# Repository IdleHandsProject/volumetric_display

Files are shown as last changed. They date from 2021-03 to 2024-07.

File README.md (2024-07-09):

# TENEX - Open Source Volumetric OLED Display

## Check out the video! - Click the Image

Volumetric OLED Display on Youtube (https://youtu.be/sVv1oc14X1w)

Control up to ten transparent OLED displays using your favourite Feather board.

Find the BOM here: https://www.findchips.com/org/10-open-hardware/list/208915-tenex-project

Shield: [][cc-by-sa]

This work is licensed under a
[Creative Commons Attribution-ShareAlike 4.0 International License][cc-by-sa].

[][cc-by-sa]

[cc-by-sa]: http://creativecommons.org/licenses/by-sa/4.0/
[cc-by-sa-image]: https://licensebuttons.net/l/by-sa/4.0/88x31.png
[cc-by-sa-shield]: https://img.shields.io/badge/License-CC%20BY--SA%204.0-lightgrey.svg

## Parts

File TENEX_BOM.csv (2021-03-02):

Manufacturer Part Number | Manufacturer | Digi-Key Part Number | Customer Reference | Reference Designator | Packaging | Part Status | Quantity | Unit Price | Extended Price | Quantity Available | Mfg Std Lead Time | Description | RoHS Status | Lead Free Status | REACH Status
CC0805MRX7R8BB104 | Yageo | 311-4348-1-ND | C3 C6 C8 C12 C15 C17 C24 C30 |  | Cut Tape (CT) | Active | 8 | 0.16000 | $1.28 | 764 | 20 Weeks | CAP CER 0.1UF 25V X7R 0805 | ROHS3 Compliant | Lead free | REACH Unaffected
CC0805MKX7R8BB475 | Yageo | 311-3509-2-ND | C4 C7 C9 C10 C13 C16 C19 C22 C25 C28 C31 |  | Tape & Reel (TR) | Active | 11 | 0.00000 | $0.00 | 9539 | 24 Weeks | CAP CER 4.7UF 25V X7R 0805 | ROHS3 Compliant | Lead free | REACH Unaffected
CC0805KKX5R8BB106 | Yageo | 311-1869-1-ND | C1 C5 C11 C14 C23 C29 |  | Cut Tape (CT) | Active | 6 | 0.72000 | $4.32 | 618478 | 52 Weeks | CAP CER 10UF 25V X5R 0805 | ROHS3 Compliant | Lead free | REACH Unaffected
CC0805MKX5R5BB226 | Yageo | 311-1464-1-ND | C2 |  | Cut Tape (CT) | Active | 1 | 0.77000 | $0.77 | 151111 | 24 Weeks | CAP CER 22UF 6.3V X5R 0805 | ROHS3 Compliant | Lead free | REACH Unaffected
NSVRB521S30T1G | ON Semiconductor | NSVRB521S30T1GOSCT-ND | D1 |  | Cut Tape (CT) | Active | 1 | 0.54000 | $0.54 | 0 | 46 Weeks | DIODE SCHOTTKY 30V 200MA SOD523 | ROHS3 Compliant | Lead free | REACH Unaffected
694106301002 | Würth Elektronik | 732-5930-ND | J1 |  | Bulk | Active | 1 | 1.30000 | $1.30 | 356 | 10 Weeks | CONN PWR JACK 2.1X5.5MM SOLDER | ROHS3 Compliant | Lead free | REACH Unaffected
PS1240P02BT | TDK Corporation | 445-2525-1-ND | LS1 |  | Cut Tape (CT) | Active | 1 | 0.88000 | $0.88 | 25024 | 8 Weeks | AUDIO PIEZO TRANSDUCER 30V TH | ROHS3 Compliant | Lead free | Not Available
RC0805JR-07470RL | Yageo | 311-470ARCT-ND | R29 |  | Cut Tape (CT) | Active | 1 | 0.14000 | $0.14 | 663861 | 20 Weeks | RES SMD 470 OHM 5% 1/8W 0805 | ROHS3 Compliant | Lead free | REACH Unaffected
RT0805FRE074K7L | Yageo | YAG3364CT-ND | R26 R27 R28 |  | Cut Tape (CT) | Active | 3 | 0.14000 | $0.42 | 12032 | 20 Weeks | RES SMD 4.7K OHM 1% 1/8W 0805 | ROHS3 Compliant | Lead free | REACH Unaffected
AC0805FR-0724KL | Yageo | 13-AC0805FR-0724KLCT-ND | R20 |  | Cut Tape (CT) | Active | 1 | 0.14000 | $0.14 | 2490 | 20 Weeks | RES SMD 24K OHM 1% 1/8W 0805 | ROHS3 Compliant | Lead free | REACH Unaffected
RT0805FRE0775KL | Yageo | 13-RT0805FRE0775KLCT-ND | R18 |  | Cut Tape (CT) | Active | 1 | 0.14000 | $0.14 | 3596 | 20 Weeks | RES SMD 75K OHM 1% 1/8W 0805 | ROHS3 Compliant | Lead free | REACH Unaffected
RMCF0805FG100K | Stackpole Electronics Inc | RMCF0805FG100KCT-ND | R2 R3 R4 R5 R6 R7 R8 R9 R10 R11 |  | Cut Tape (CT) | Active | 10 | 0.03800 | $0.38 | 29256 | 21 Weeks | RES 100K OHM 1% 1/8W 0805 | ROHS3 Compliant | Lead free | REACH Unaffected
RMCF0805FG100K | Stackpole Electronics Inc | RMCF0805FG100KCT-ND | R17 R19 |  | Cut Tape (CT) | Active | 2 | 0.03800 | $0.38 | 29256 | 21 Weeks | RES 100K OHM 1% 1/8W 0805 | ROHS3 Compliant | Lead free | REACH Unaffected
RC0805FR-075K1L | Yageo | 311-5.10KCRCT-ND | R1 |  | Cut Tape (CT) | Active | 1 | 0.14000 | $0.14 | 1557587 | 20 Weeks | RES SMD 5.1K OHM 1% 1/8W 0805 | ROHS3 Compliant | Lead free | REACH Unaffected
RC0805FR-07910KL | Yageo | YAG3336CT-ND | R12 R13 R14 R15 R16 R21 R22 R23 R24 R25 |  | Cut Tape (CT) | Active | 10 | 0.05800 | $0.58 | 1287 | 20 Weeks | RES SMD 910K OHM 1% 1/8W 0805 | ROHS3 Compliant | Lead free | REACH Unaffected
MPM3606AGQV-P | Monolithic Power Systems Inc. | 1589-1247-1-ND | U7 |  | Cut Tape (CT) | Active | 1 | 4.18000 | $4.18 | 1870 | 16 Weeks | DC DC CONVERTER 0.8-18.48V | ROHS3 Compliant | Lead free | REACH Unaffected
MPU-6050 | TDK InvenSense | 1428-1007-1-ND | U13 |  | Cut Tape (CT) | Not For New Designs | 1 | 10.92000 | $10.92 | 5786 | 22 Weeks | IMU ACCEL/GYRO 3-AXIS I2C 24QFN | ROHS3 Compliant | Lead free | Not Available
62674-241121ALF | Amphenol ICC (FCI) | 609-1210-1-ND | U2 U3 U4 U5 U6 U8 U9 U10 U11 U12 |  | Cut Tape (CT) | Active | 10 | 0.99500 | $9.95 | 0 | 17 Weeks | CONN FFC VERT 24POS 0.50MM SMD | RoHS Compliant | Lead free | REACH Unaffected
3857 | Adafruit Industries LLC | 1528-2648-ND | U1 |  | Bulk | Active | 1 | 31.18000 | $31.18 | 284 | 2 Weeks | FEATHER M4 EXPRESS ATSAMD51J19 | ROHS3 Compliant | Not Available | Not Available

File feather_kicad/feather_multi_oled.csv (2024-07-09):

Source: | N:\idlehandsdev\Projects\volumetric_display\feather_kicad\feather_multi_oled.kicad_sch
Date: | 2024-07-09 9:34:55 AM
Tool: | Eeschema 7.0.9
Generator: | C:\Program Files\KiCad\7.0\bin\scripting\plugins/bom_csv_grouped_by_value.py
Component Count: | 71
Collated Components:
Item | Qty | Reference(s) | Value | LibPart | Footprint | Datasheet | DNP | Digikey Part No.
1 | 6 | C1, C5, C11, C14, C23, C29 | 10uF | Device:C_Small | Capacitor_SMD:C_0805_2012Metric | ~ |  | 311-1869-1-ND
2 | 1 | C2 | 22uF | Device:C_Small | Capacitor_SMD:C_0805_2012Metric | ~ |  | 311-1464-1-ND
3 | 8 | C3, C6, C8, C12, C15, C17, C24, C30 | 0.1uF | Device:C_Small | Capacitor_SMD:C_0805_2012Metric | ~ |  | 311-4348-1-ND
4 | 11 | C4, C7, C9, C10, C13, C16, C19, C22, C25, C28, C31 | 4.7uF | Device:C_Small | Capacitor_SMD:C_0805_2012Metric | ~ |  | 311-3509-2-ND
5 | 1 | D1 | RB521S30T1G | Device:D_Schottky_Small | Diode_SMD:D_SOD-523 | ~ |  | NSVRB521S30T1GOSCT-ND
6 | 1 | J1 | Barrel_Jack_Switch | Connector:Barrel_Jack_Switch | Connector_BarrelJack:BarrelJack_Wuerth_6941xx301002 | ~ |  | 732-5930-ND
7 | 1 | LS1 | Speaker_Crystal | Device:Speaker_Crystal | Buzzer_Beeper:Buzzer_TDK_PS1240P02BT_D12.2mm_H6.5mm | ~ |  | 445-2525-1-ND
8 | 1 | R1 | 5.1K 1% | Device:R_Small | Resistor_SMD:R_0805_2012Metric | ~ |  | 311-5.10KCRCT-ND
9 | 12 | R2, R3, R4, R5, R6, R7, R8, R9, R10, R11, R17, R19 | 100K | AP2112k:R_Small | Resistor_SMD:R_0805_2012Metric | ~ |  | RMCF0805FG100KCT-ND
10 | 10 | R12, R13, R14, R15, R16, R21, R22, R23, R24, R25 | 910K 1% | Device:R_Small | Resistor_SMD:R_0805_2012Metric | ~ |  | YAG3336CT-ND
11 | 1 | R18 | 75K | AP2112k:R_Small | Resistor_SMD:R_0805_2012Metric |  |  | 13-RT0805FRE0775KLCT-ND
12 | 1 | R20 | 24K | AP2112k:R_Small | Resistor_SMD:R_0805_2012Metric |  |  | 13-AC0805FR-0724KLCT-ND
13 | 3 | R26, R27, R28 | 4.7K | Device:R_Small | Resistor_SMD:R_0805_2012Metric | ~ |  | YAG3364CT-ND
14 | 1 | R29 | 470R | Device:R_Small | Resistor_SMD:R_0805_2012Metric | ~ |  | 311-470ARCT-ND
15 | 1 | U1 | feather | project_lib:feather | Adafruit_FeatherWing:PCB_FeatherWing |  |  | 1528-2648-ND
16 | 10 | U2, U3, U4, U5, U6, U8, U9, U10, U11, U12 | SSD1309_transparent_oled | project_lib:SSD1309_transparent_oled | project_footprints:FCI_62674-241121ALF |  |  | WM7986CT-ND
17 | 1 | U7 | MPM36XX | project_lib:MPM36XX | project_footprints:MPM3606AGQV-Z | https://www.monolithicpower.com/en/documentview/productdocument/index/version/2/document_type/Datasheet/lang/en/sku/MPM3606AGQV/document_id/2104 |  | 1589-1247-1-ND
18 | 1 | U13 | MPU-6050 | feather_multi_oled-rescue:MPU-6050-Sensor_Motion | Sensor_Motion:InvenSense_QFN-24_4x4mm_P0.5mm | https://store.invensense.com/datasheets/invensense/MPU-6050_DataSheet_V3%204.pdf |  | 1428-1007-1-ND

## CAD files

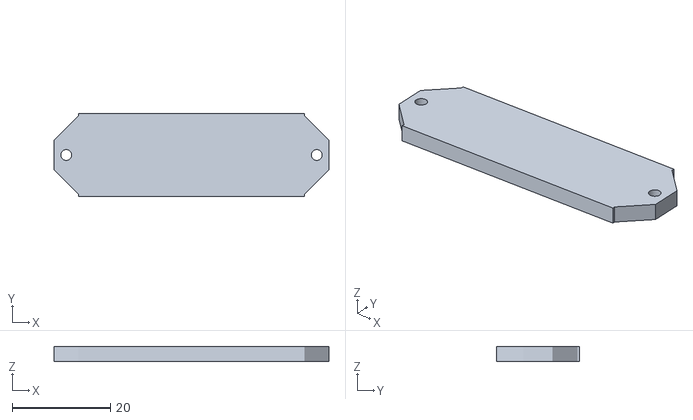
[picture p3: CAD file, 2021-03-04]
CAD/Display_Top (lasercut if possible).stl
56.0 x 17.0 x 3.00

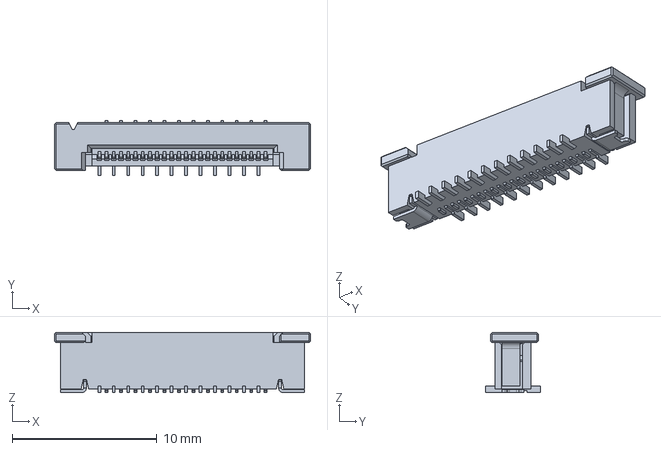
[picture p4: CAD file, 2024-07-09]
feather_kicad/project_libs/3dPackages/c-2-1734742-4-o-3d.stp
17.7 x 3.80 x 4.15 mm

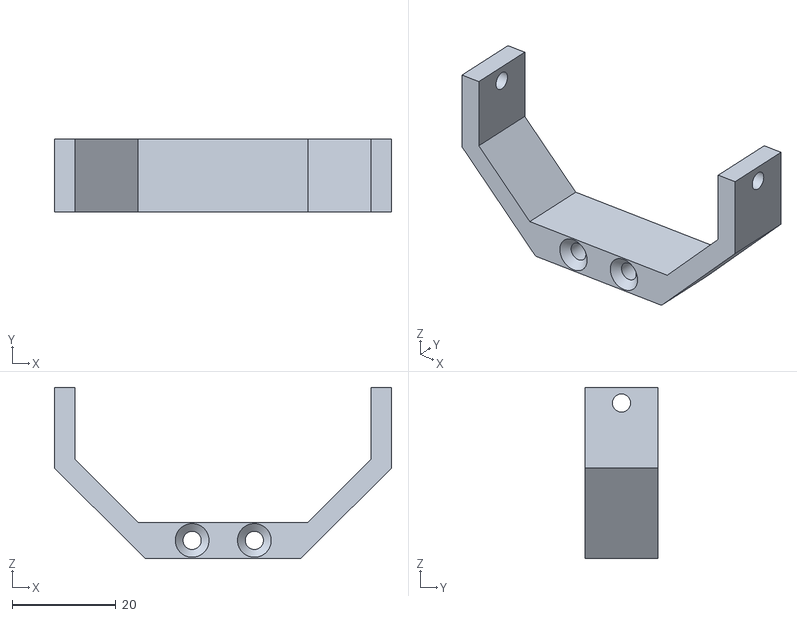
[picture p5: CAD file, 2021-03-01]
CAD/Head_Arm.stl
65.0 x 14.0 x 33.0

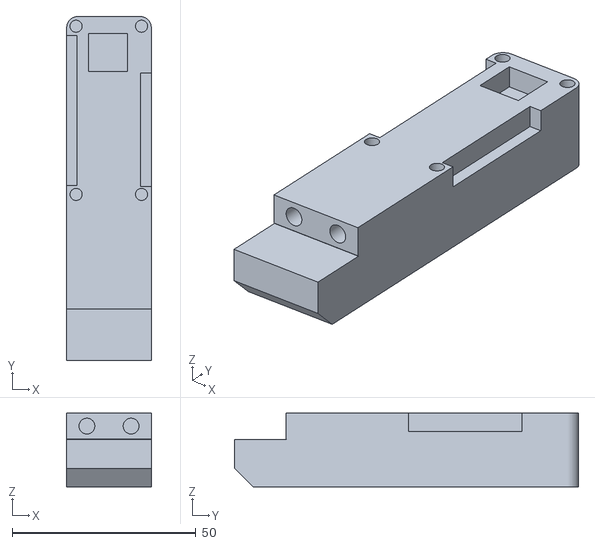
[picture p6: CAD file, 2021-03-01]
CAD/Head_Holder_Single.stl
23.0 x 93.5 x 20.0

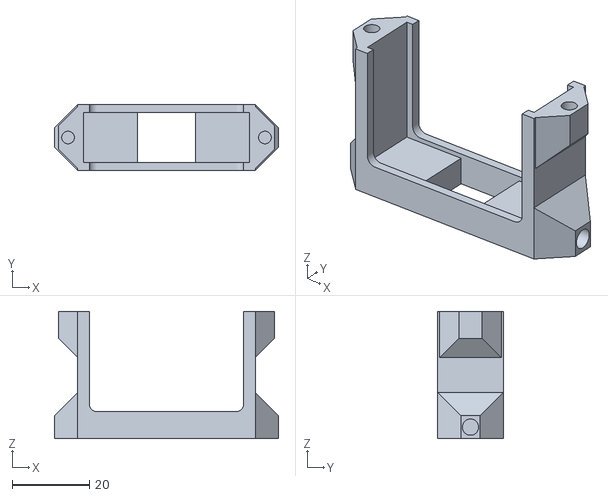
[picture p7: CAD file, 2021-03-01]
CAD/OLED_Holder.stl
58.0 x 17.0 x 33.0

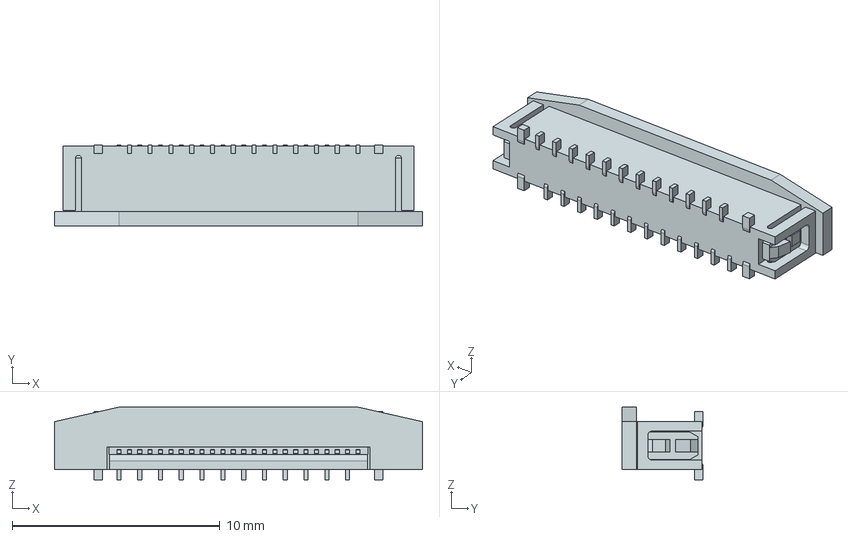
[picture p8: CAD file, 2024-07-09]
feather_kicad/project_libs/3dPackages/525592452.stp
17.7 x 3.90 x 3.50 mm

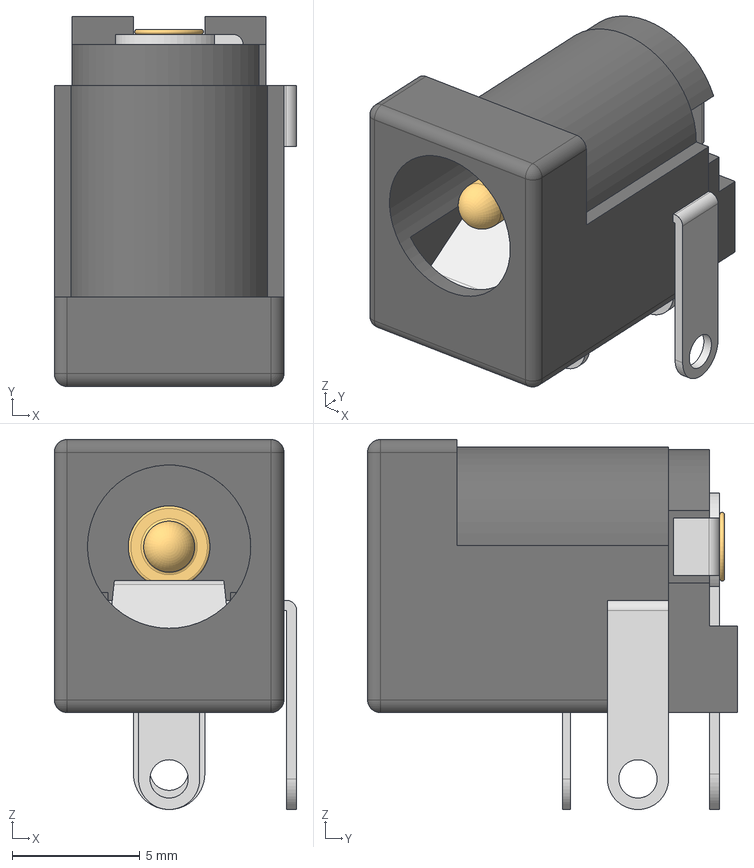
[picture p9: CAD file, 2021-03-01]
feather_kicad/project_libs/694106301002 (rev1).stp
9.50 x 14.5 x 14.5 mm
6941xx301002
694106301002_PinContact
6941xx301002_Back
6941xx301002_PinContact2
6941xx301002_PinLame
6941xx301002_PinBis

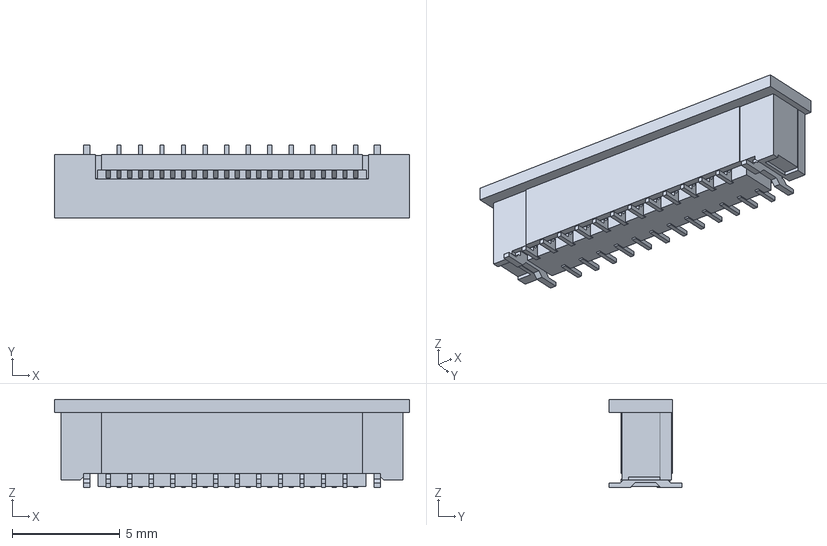
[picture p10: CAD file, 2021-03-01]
feather_kicad/project_libs/s62674_241121lf.stp
16.5 x 3.40 x 4.10 mm

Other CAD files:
feather_kicad/pcb.dxf
CAD/Display_Top (Acrylic).step

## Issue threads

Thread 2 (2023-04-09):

BOM link in readme is broken

thijstriemstra, 2023-04-09:
https://www.findchips.com/org/10-open-hardware/list/208915-tenex-project

ZpeedTube, 2023-07-30:
Yeah, still same problem 🥲

hodginsa, 2023-11-06:
It seems like findchips disables the share link after awhile, and I have to click "share" again. It should be active again.

thijstriemstra, 2023-11-06:
unfortunately not:

> Oops! We couldn't find what you were looking for.

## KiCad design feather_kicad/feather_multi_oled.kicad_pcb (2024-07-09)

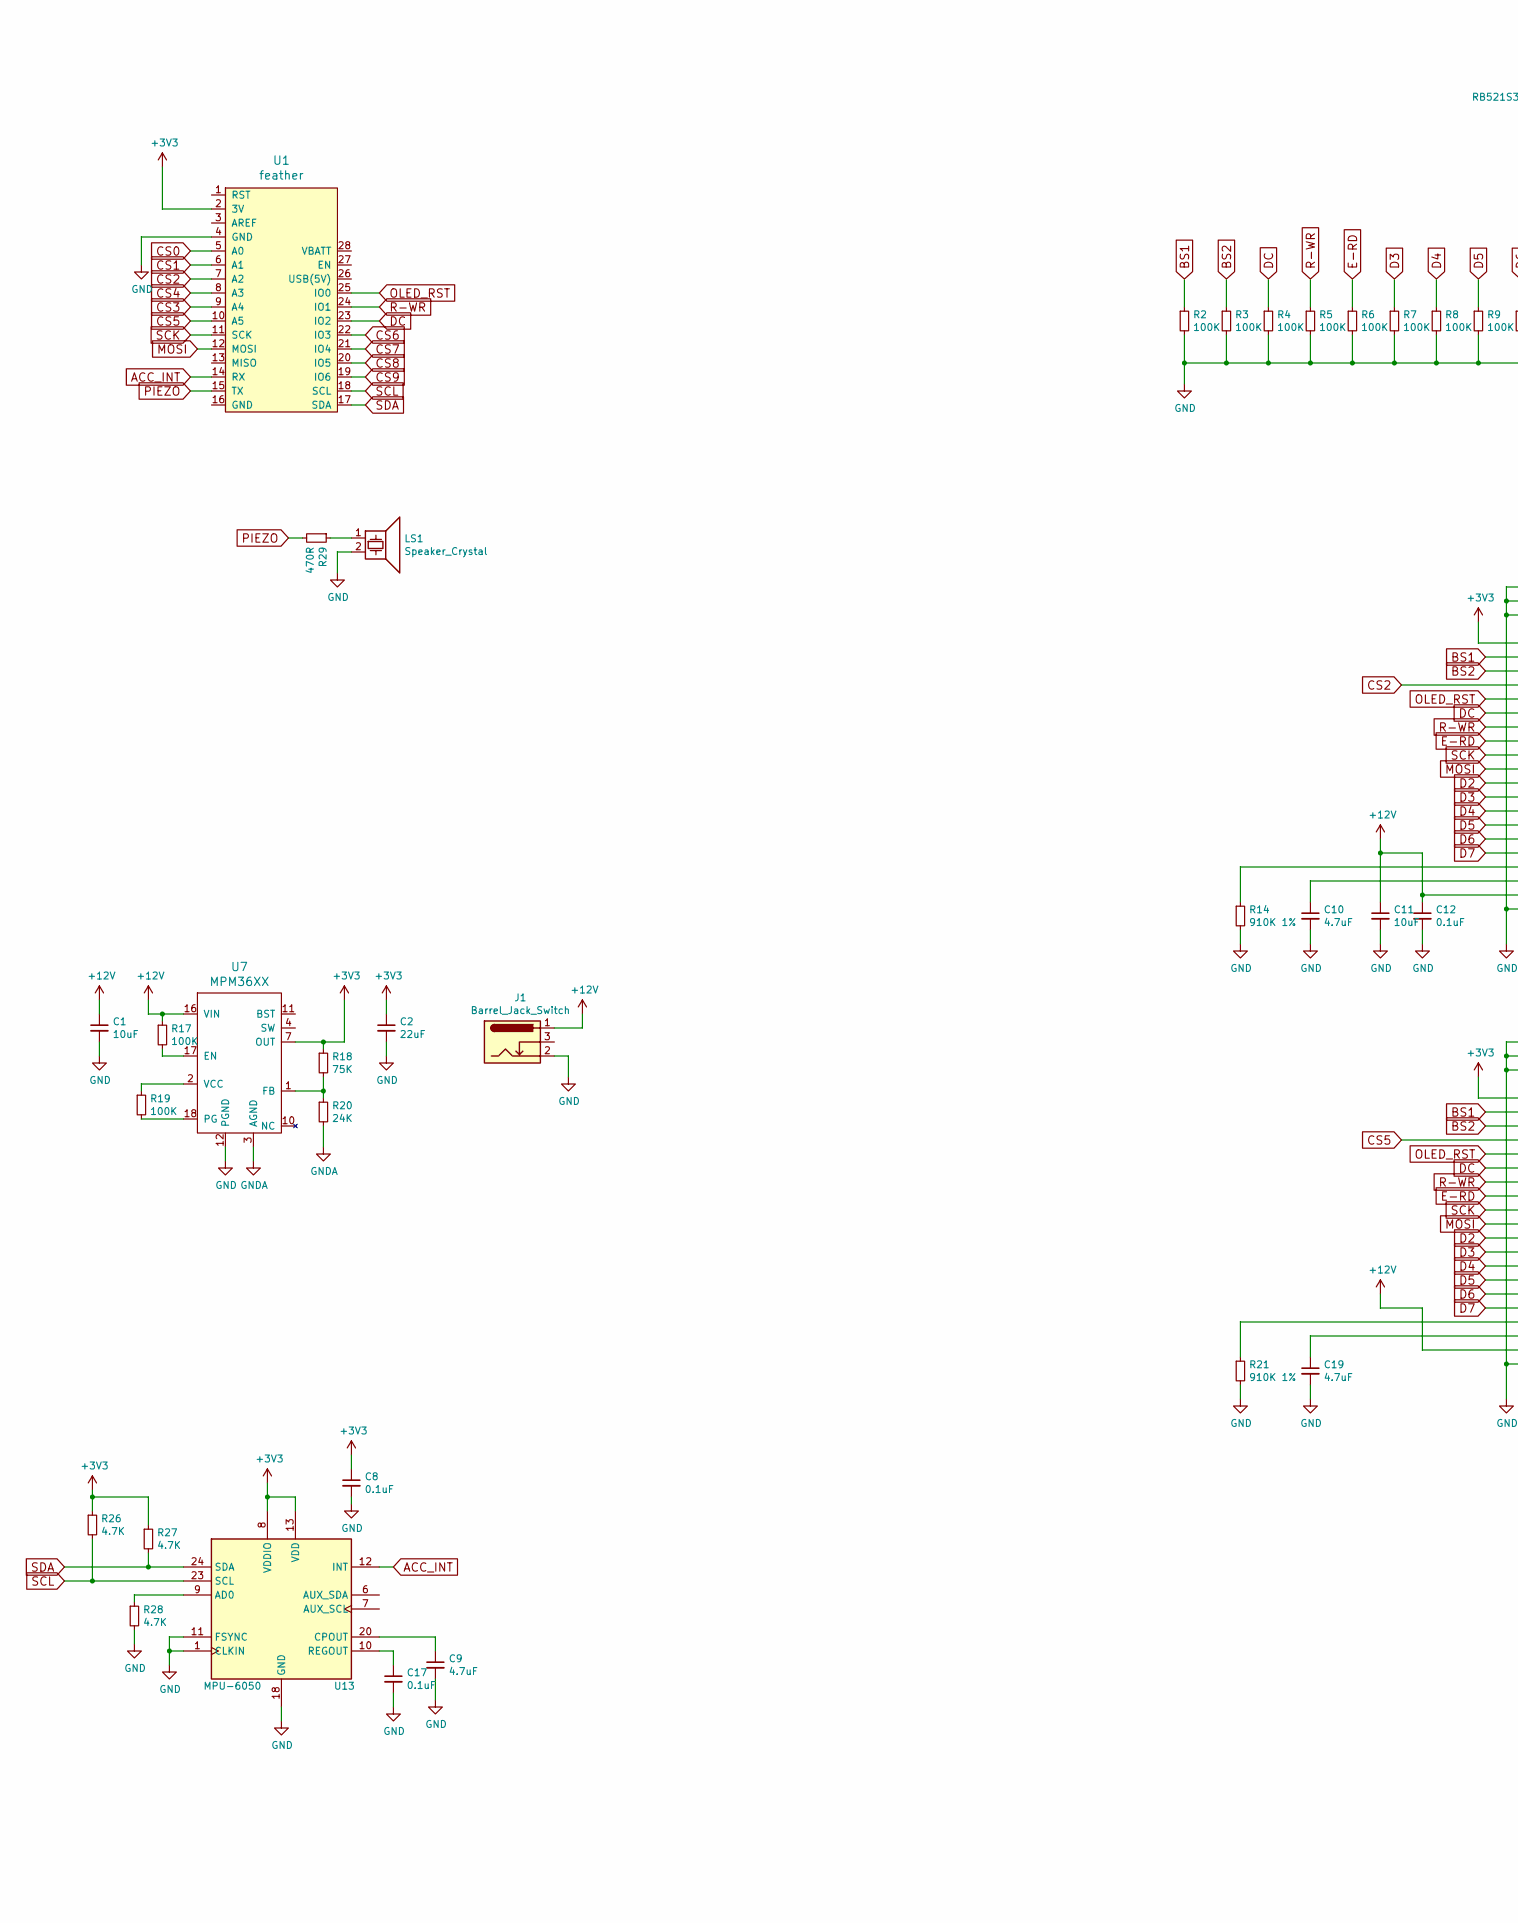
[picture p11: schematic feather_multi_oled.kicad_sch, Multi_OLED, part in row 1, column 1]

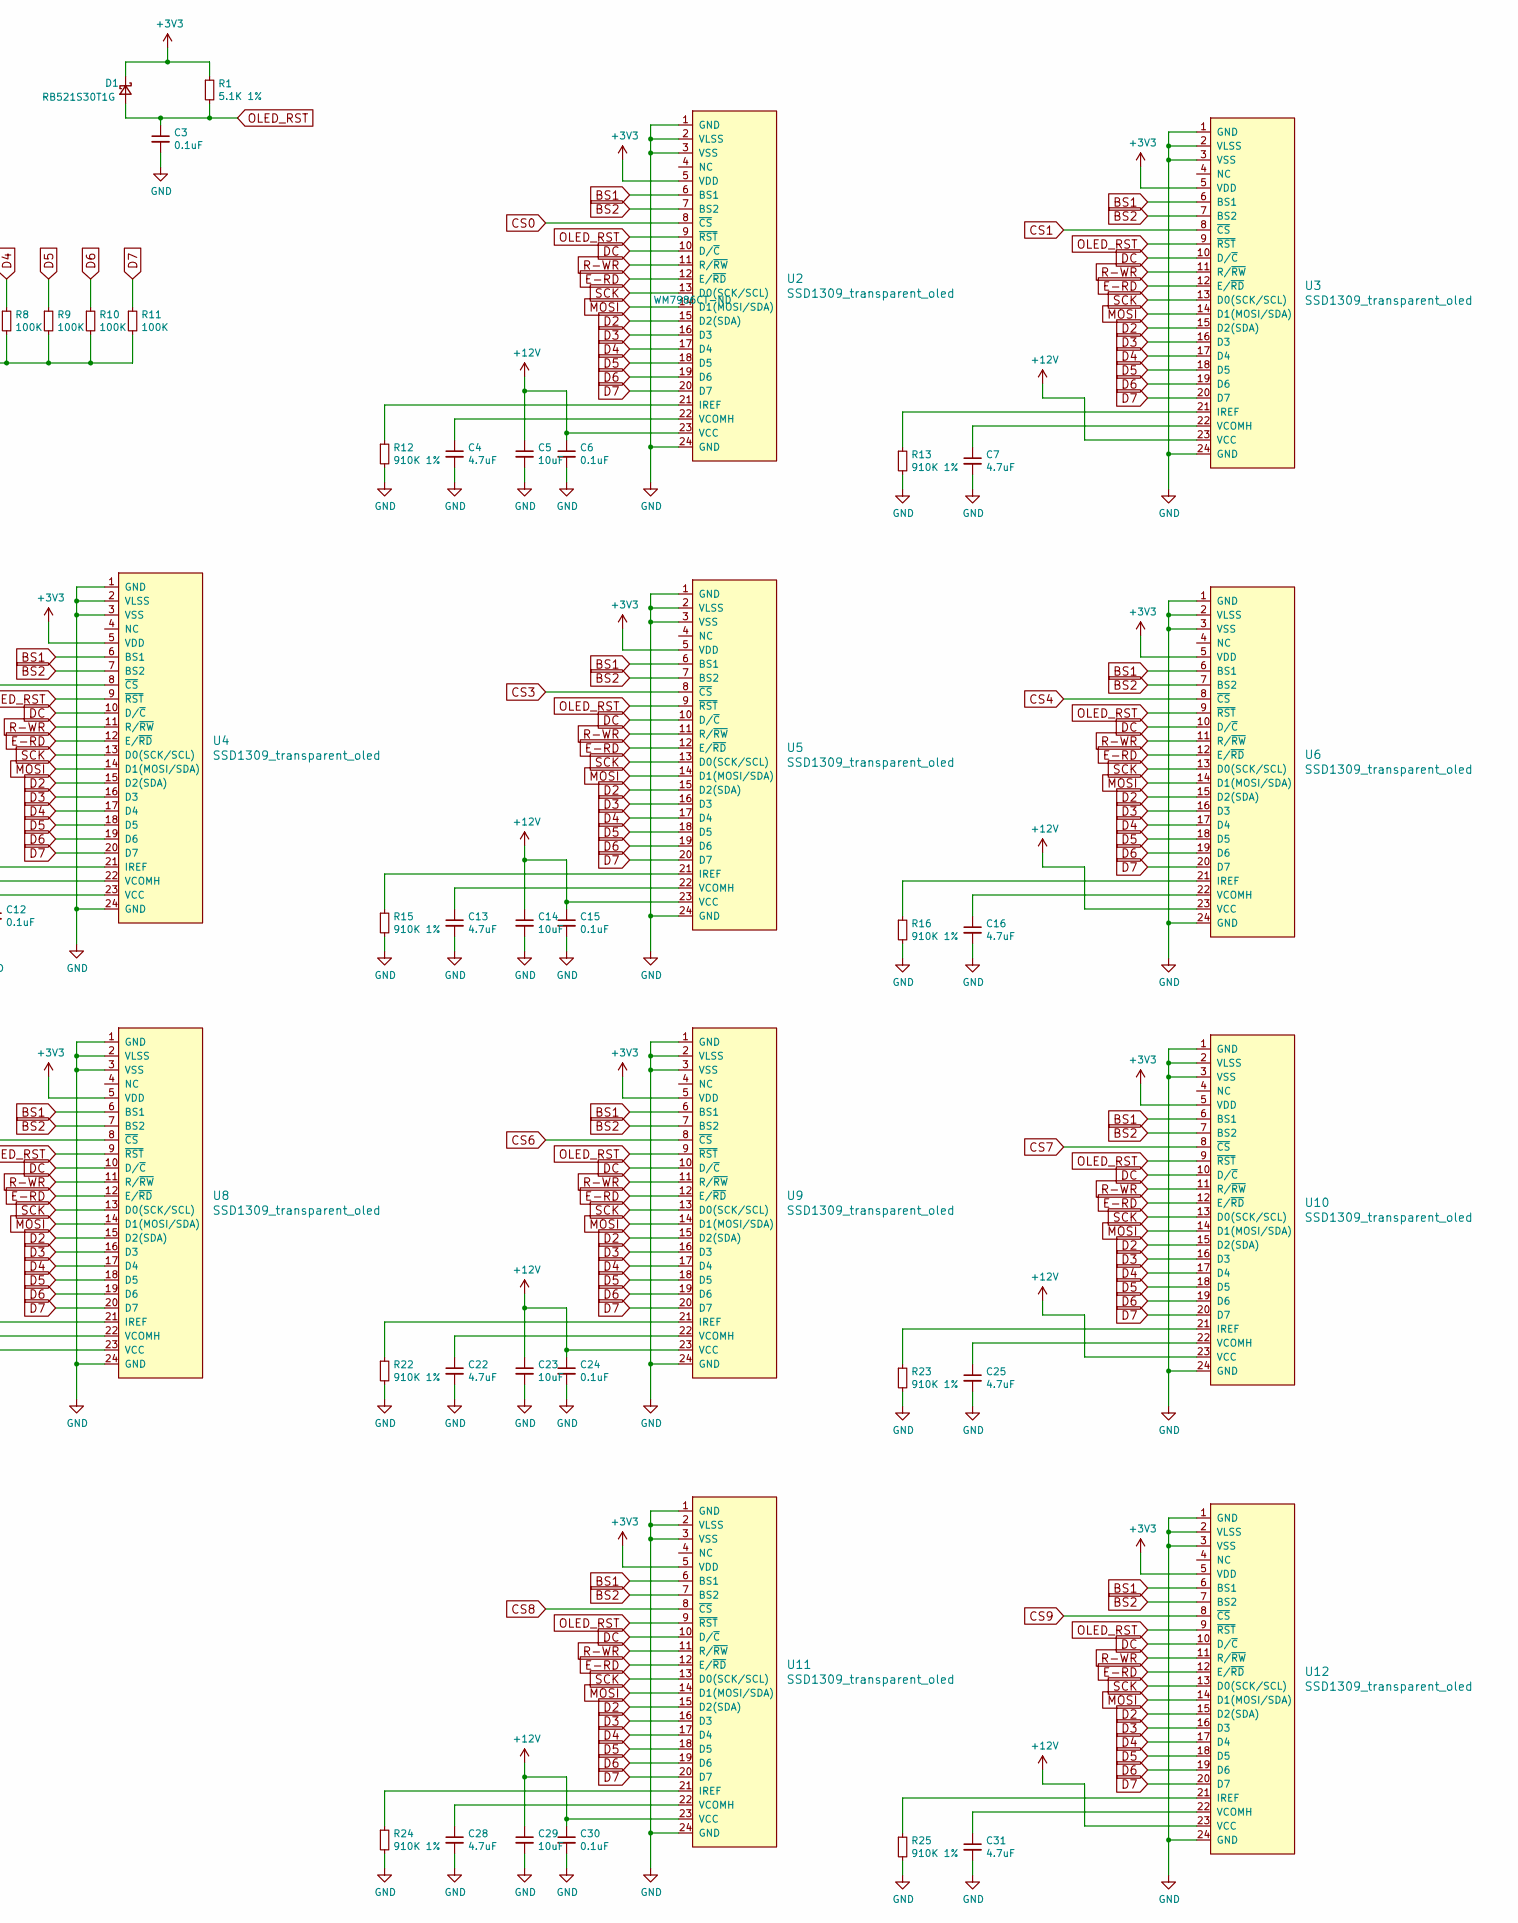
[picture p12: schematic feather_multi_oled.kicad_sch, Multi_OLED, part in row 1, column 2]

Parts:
C1, C5, C11, C14, C23, C29: 10uF; C_0805_2012Metric; Digikey Part No. 311-1869-1-ND
C2: 22uF; C_0805_2012Metric; Digikey Part No. 311-1464-1-ND
C3, C6, C8, C12, C15, C17, C24, C30: 0.1uF; C_0805_2012Metric; Digikey Part No. 311-4348-1-ND
C4, C7, C9, C10, C13, C16, C19, C22, C25, C28, C31: 4.7uF; C_0805_2012Metric; Digikey Part No. 311-3509-2-ND
D1: RB521S30T1G; D_SOD-523; Digikey Part No. NSVRB521S30T1GOSCT-ND
J1: Barrel_Jack_Switch; BarrelJack_Wuerth_6941xx301002; Digikey Part No. 732-5930-ND
LS1: Speaker_Crystal; Buzzer_TDK_PS1240P02BT_D12.2mm_H6.5mm; Digikey Part No. 445-2525-1-ND
R1: 5.1K 1%; R_0805_2012Metric; Digikey Part No. 311-5.10KCRCT-ND
R2, R3, R4, R5, R6, R7, R8, R9, R10, R11, R17, R19: 100K; R_0805_2012Metric; Digikey Part No. RMCF0805FG100KCT-ND
R12, R13, R14, R15, R16, R21, R22, R23, R24, R25: 910K 1%; R_0805_2012Metric; Digikey Part No. YAG3336CT-ND
R18: 75K; R_0805_2012Metric; Digikey Part No. 13-RT0805FRE0775KLCT-ND
R20: 24K; R_0805_2012Metric; Digikey Part No. 13-AC0805FR-0724KLCT-ND
R26, R27, R28: 4.7K; R_0805_2012Metric; Digikey Part No. YAG3364CT-ND
R29: 470R; R_0805_2012Metric; Digikey Part No. 311-470ARCT-ND
U1: feather; PCB_FeatherWing; Digikey Part No. 1528-2648-ND
U2, U3, U4, U5, U6, U8, U9, U10, U11, U12: SSD1309_transparent_oled; FCI_62674-241121ALF; Digikey Part No. WM7986CT-ND
U7: MPM36XX; MPM3606AGQV-Z; Digikey Part No. 1589-1247-1-ND
U13: MPU-6050; InvenSense_QFN-24_4x4mm_P0.5mm; Digikey Part No. 1428-1007-1-ND

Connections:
+3V3: C2.1, C8.1, D1.1 (K), R1.1, R18.1, R26.1, R27.1, U1.2 (3V), U2.5 (VDD), U3.5 (VDD), U4.5 (VDD), U5.5 (VDD), U6.5 (VDD), U7.7 (OUT), U8.5 (VDD), U9.5 (VDD), U10.5 (VDD), U11.5 (VDD), U12.5 (VDD), U13.8 (VDDIO), U13.13 (VDD)
+12V: C1.1, C5.1, C6.1, C11.1, C12.1, C14.1, C15.1, C23.1, C24.1, C29.1, C30.1, J1.1, R17.1, U2.23 (VCC), U3.23 (VCC), U4.23 (VCC), U5.23 (VCC), U6.23 (VCC), U7.16 (VIN), U8.23 (VCC), U9.23 (VCC), U10.23 (VCC), U11.23 (VCC), U12.23 (VCC)
ACC_INT: U1.14 (RX), U13.12 (INT)
BS1: R2.1, U2.6 (BS1), U3.6 (BS1), U4.6 (BS1), U5.6 (BS1), U6.6 (BS1), U8.6 (BS1), U9.6 (BS1), U10.6 (BS1), U11.6 (BS1), U12.6 (BS1)
BS2: R3.1, U2.7 (BS2), U3.7 (BS2), U4.7 (BS2), U5.7 (BS2), U6.7 (BS2), U8.7 (BS2), U9.7 (BS2), U10.7 (BS2), U11.7 (BS2), U12.7 (BS2)
CS0: U1.5 (A0), U2.8 (~CS)
CS1: U1.6 (A1), U3.8 (~CS)
CS2: U1.7 (A2), U4.8 (~CS)
CS3: U1.9 (A4), U5.8 (~CS)
CS4: U1.8 (A3), U6.8 (~CS)
CS5: U1.10 (A5), U8.8 (~CS)
CS6: U1.22 (IO3), U9.8 (~CS)
CS7: U1.21 (IO4), U10.8 (~CS)
CS8: U1.20 (IO5), U11.8 (~CS)
CS9: U1.19 (IO6), U12.8 (~CS)
D2: U2.15 (D2(SDA)), U3.15 (D2(SDA)), U4.15 (D2(SDA)), U5.15 (D2(SDA)), U6.15 (D2(SDA)), U8.15 (D2(SDA)), U9.15 (D2(SDA)), U10.15 (D2(SDA)), U11.15 (D2(SDA)), U12.15 (D2(SDA))
D3: R7.1, U2.16 (D3), U3.16 (D3), U4.16 (D3), U5.16 (D3), U6.16 (D3), U8.16 (D3), U9.16 (D3), U10.16 (D3), U11.16 (D3), U12.16 (D3)
D4: R8.1, U2.17 (D4), U3.17 (D4), U4.17 (D4), U5.17 (D4), U6.17 (D4), U8.17 (D4), U9.17 (D4), U10.17 (D4), U11.17 (D4), U12.17 (D4)
D5: R9.1, U2.18 (D5), U3.18 (D5), U4.18 (D5), U5.18 (D5), U6.18 (D5), U8.18 (D5), U9.18 (D5), U10.18 (D5), U11.18 (D5), U12.18 (D5)
D6: R10.1, U2.19 (D6), U3.19 (D6), U4.19 (D6), U5.19 (D6), U6.19 (D6), U8.19 (D6), U9.19 (D6), U10.19 (D6), U11.19 (D6), U12.19 (D6)
D7: R11.1, U2.20 (D7), U3.20 (D7), U4.20 (D7), U5.20 (D7), U6.20 (D7), U8.20 (D7), U9.20 (D7), U10.20 (D7), U11.20 (D7), U12.20 (D7)
DC: R4.1, U1.23 (IO2), U2.10 (D/~C), U3.10 (D/~C), U4.10 (D/~C), U5.10 (D/~C), U6.10 (D/~C), U8.10 (D/~C), U9.10 (D/~C), U10.10 (D/~C), U11.10 (D/~C), U12.10 (D/~C)
E-RD: R6.1, U2.12 (E/~RD), U3.12 (E/~RD), U4.12 (E/~RD), U5.12 (E/~RD), U6.12 (E/~RD), U8.12 (E/~RD), U9.12 (E/~RD), U10.12 (E/~RD), U11.12 (E/~RD), U12.12 (E/~RD)
GND: C1.2, C2.2, C3.2, C4.2, C5.2, C6.2, C7.2, C8.2, C9.2, C10.2, C11.2, C12.2, C13.2, C14.2, C15.2, C16.2, C17.2, C19.2, C22.2, C23.2, C24.2, C25.2, C28.2, C29.2, C30.2, C31.2, J1.2, LS1.2, R2.2, R3.2, R4.2, R5.2, R6.2, R7.2, R8.2, R9.2, R10.2, R11.2, R12.2, R13.2, R14.2, R15.2, R16.2, R21.2, R22.2, R23.2, R24.2, R25.2, R28.2, U1.4 (GND), U2.1 (GND), U2.2 (VLSS), U2.3 (VSS), U2.24 (GND), U3.1 (GND), U3.2 (VLSS), U3.3 (VSS), U3.24 (GND), U4.1 (GND), U4.2 (VLSS), U4.3 (VSS), U4.24 (GND), U5.1 (GND), U5.2 (VLSS), U5.3 (VSS), U5.24 (GND), U6.1 (GND), U6.2 (VLSS), U6.3 (VSS), U6.24 (GND), U7.12 (PGND), U8.1 (GND), U8.2 (VLSS), U8.3 (VSS), U8.24 (GND), U9.1 (GND), U9.2 (VLSS), U9.3 (VSS), U9.24 (GND), U10.1 (GND), U10.2 (VLSS), U10.3 (VSS), U10.24 (GND), U11.1 (GND), U11.2 (VLSS), U11.3 (VSS), U11.24 (GND), U12.1 (GND), U12.2 (VLSS), U12.3 (VSS), U12.24 (GND), U13.1 (CLKIN), U13.11 (FSYNC), U13.18 (GND)
GNDA: R20.2, U7.3 (AGND)
MOSI: U1.12 (MOSI), U2.14 (D1(MOSI/SDA)), U3.14 (D1(MOSI/SDA)), U4.14 (D1(MOSI/SDA)), U5.14 (D1(MOSI/SDA)), U6.14 (D1(MOSI/SDA)), U8.14 (D1(MOSI/SDA)), U9.14 (D1(MOSI/SDA)), U10.14 (D1(MOSI/SDA)), U11.14 (D1(MOSI/SDA)), U12.14 (D1(MOSI/SDA))
unnamed: C4.1, U2.22 (VCOMH)
unnamed: C7.1, U3.22 (VCOMH)
unnamed: C9.1, U13.20 (CPOUT)
unnamed: C10.1, U4.22 (VCOMH)
unnamed: C13.1, U5.22 (VCOMH)
unnamed: C16.1, U6.22 (VCOMH)
unnamed: C17.1, U13.10 (REGOUT)
unnamed: C19.1, U8.22 (VCOMH)
unnamed: C22.1, U9.22 (VCOMH)
unnamed: C25.1, U10.22 (VCOMH)
unnamed: C28.1, U11.22 (VCOMH)
unnamed: C31.1, U12.22 (VCOMH)
unnamed: LS1.1, R29.1
unnamed: R12.1, U2.21 (IREF)
unnamed: R13.1, U3.21 (IREF)
unnamed: R14.1, U4.21 (IREF)
unnamed: R15.1, U5.21 (IREF)
unnamed: R16.1, U6.21 (IREF)
unnamed: R17.2, U7.17 (EN)
unnamed: R18.2, R20.1, U7.1 (FB)
unnamed: R19.1, U7.2 (VCC)
unnamed: R19.2, U7.18 (PG)
unnamed: R21.1, U8.21 (IREF)
unnamed: R22.1, U9.21 (IREF)
unnamed: R23.1, U10.21 (IREF)
unnamed: R24.1, U11.21 (IREF)
unnamed: R25.1, U12.21 (IREF)
unnamed: R28.1, U13.9 (AD0)
OLED_RST: C3.1, D1.2 (A), R1.2, U1.25 (IO0), U2.9 (~RST), U3.9 (~RST), U4.9 (~RST), U5.9 (~RST), U6.9 (~RST), U8.9 (~RST), U9.9 (~RST), U10.9 (~RST), U11.9 (~RST), U12.9 (~RST)
PIEZO: R29.2, U1.15 (TX)
R-WR: R5.1, U1.24 (IO1), U2.11 (R/~RW), U3.11 (R/~RW), U4.11 (R/~RW), U5.11 (R/~RW), U6.11 (R/~RW), U8.11 (R/~RW), U9.11 (R/~RW), U10.11 (R/~RW), U11.11 (R/~RW), U12.11 (R/~RW)
SCK: U1.11 (SCK), U2.13 (D0(SCK/SCL)), U3.13 (D0(SCK/SCL)), U4.13 (D0(SCK/SCL)), U5.13 (D0(SCK/SCL)), U6.13 (D0(SCK/SCL)), U8.13 (D0(SCK/SCL)), U9.13 (D0(SCK/SCL)), U10.13 (D0(SCK/SCL)), U11.13 (D0(SCK/SCL)), U12.13 (D0(SCK/SCL))
SCL: R26.2, U1.18 (SCL), U13.23 (SCL)
SDA: R27.2, U1.17 (SDA), U13.24 (SDA)

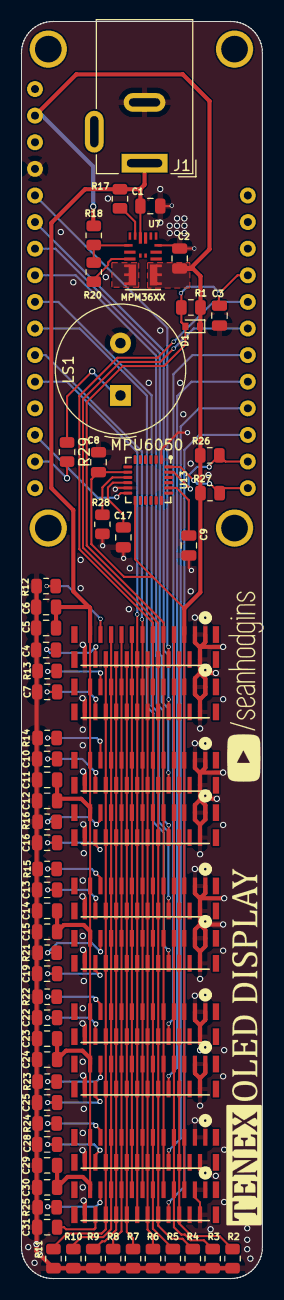
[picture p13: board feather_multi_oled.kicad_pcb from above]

Board: 2 copper layers, 23.0 x 120.0 mm, 70 parts (0 on the bottom side), 58 nets.

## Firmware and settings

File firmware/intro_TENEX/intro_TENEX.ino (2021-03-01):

#include <Arduino.h>
#include <math.h>

// I2Cdev and MPU6050 must be installed as libraries, or else the .cpp/.h files
// for both classes must be in the include path of your project
#include "I2Cdev.h"
#include "MPU6050.h"

// Arduino Wire library is required if I2Cdev I2CDEV_ARDUINO_WIRE implementation
// is used in I2Cdev.h
#if I2CDEV_IMPLEMENTATION == I2CDEV_ARDUINO_WIRE
#include "Wire.h"
#endif

#include <U8g2lib.h>

#ifdef U8X8_HAVE_HW_SPI
#include <SPI.h>
#endif
#ifdef U8X8_HAVE_HW_I2C
#include <Wire.h>
#endif


//MAX RESOLUTION PIXELS (X/Y is the resolution of a single display, Z is depth)
#define X_RES 128
#define Y_RES 56
#define Z_RES 10
#define Z_DISTANCE 2
#define acc_SCALE 10

#define X_MAX 12700
#define Y_MAX 5600
#define Z_MAX 9000

int ball_xyz[3] = {64000, 25000, 5000};
int max_xyz[3] = {127000, 55000, 9000};
int vel_xyz[3] = {0, 0, 0};
int ball_r = 8000;
float resitution = 1.3;

MPU6050 accelgyro;

int16_t ax, ay, az;
int16_t gx, gy, gz;

#define OUTPUT_READABLE_ACCELGYRO

int displays [10] = {A0, A1, A2, A3, A4, A5, 10, 9, 6, 5};

bool volumeBuffer[128][56][10] = {0};

//U8G2_SSD1309_128X64_NONAME0_F_4W_HW_SPI oled(U8G2_MIRROR, /* cs=*/ -1, /* dc=*/ 11, /* reset=*/ 13);
U8G2_SSD1309_128X64_NONAME0_F_4W_HW_SPI oled(U8G2_R0, /* cs=*/ -1, /* dc=*/ 11, /* reset=*/ 13);

#define X_MAX 12700
#define Y_MAX 5600
#define Z_MAX 9000

#define PIEZO 1


#define SH_width 128
#define SH_height 64
unsigned const char SH[] = {
  0x00, 0x00, 0x00, 0x00, 0x00, 0x00, 0x00, 0x00, 0x00, 0x00, 0x00, 0x00,
  0x00, 0x00, 0x00, 0x00, 0x00, 0x00, 0x00, 0x00, 0x00, 0x00, 0x00, 0x00,
  0x00, 0x00, 0x00, 0x00, 0x00, 0x00, 0x00, 0x00, 0x00, 0x00, 0x00, 0x00,
  0x00, 0x00, 0x00, 0x00, 0x00, 0x00, 0x00, 0x00, 0x00, 0x00, 0x00, 0x00,
  0x00, 0x00, 0x00, 0x00, 0x00, 0x00, 0x00, 0x00, 0x00, 0x00, 0x00, 0x00,
  0x00, 0x00, 0x00, 0x00, 0x00, 0x00, 0x00, 0x00, 0x00, 0x00, 0x00, 0x00,
  0x00, 0x00, 0x00, 0x00, 0x00, 0x00, 0x00, 0x00, 0x00, 0x00, 0x00, 0x00,
  0x00, 0xF8, 0x7F, 0x00, 0x00, 0x00, 0x00, 0x00, 0x00, 0x00, 0x00, 0x00,
  0x00, 0x00, 0x00, 0x00, 0xD0, 0xFF, 0xFF, 0x00, 0x00, 0x00, 0x00, 0x00,
  0x00, 0x00, 0x00, 0x00, 0x00, 0x00, 0x00, 0x00, 0xFF, 0xFF, 0xF6, 0x03,
  0x00, 0x00, 0x00, 0x00, 0x00, 0x00, 0x00, 0x00, 0x00, 0x00, 0x00, 0xF0,
  0xFF, 0x02, 0x00, 0x02, 0x00, 0x00, 0x00, 0x00, 0x00, 0x00, 0x00, 0x00,
  0x00, 0x00, 0x00, 0xFF, 0x1F, 0x00, 0x00, 0x00, 0x00, 0x00, 0x00, 0x00,
  0x00, 0x00, 0x00, 0x00, 0x00, 0x00, 0xE0, 0xFF, 0x01, 0x00, 0x00, 0x00,
  0x00, 0x00, 0x00, 0x00, 0x00, 0x00, 0x00, 0x00, 0x00, 0x00, 0xFC, 0x3F,
  0x00, 0x00, 0x00, 0x00, 0x00, 0x00, 0x00, 0x00, 0x00, 0x00, 0x00, 0x00,
  0x00, 0x00, 0xFF, 0x07, 0x00, 0x00, 0x00, 0x00, 0x00, 0x00, 0x00, 0x00,
  0x00, 0x00, 0x00, 0x00, 0x00, 0x80, 0xFF, 0x00, 0x00, 0x00, 0x00, 0x00,
  0x00, 0x00, 0x00, 0x00, 0x00, 0x00, 0x00, 0x00, 0x00, 0x00, 0xFF, 0x00,
  0x00, 0x00, 0x00, 0x00, 0x00, 0x00, 0x00, 0x00, 0x00, 0x00, 0x00, 0x00,
  0x00, 0x00, 0xFF, 0x0F, 0x00, 0x00, 0x00, 0x00, 0x00, 0x00, 0x00, 0x00,
  0x00, 0x00, 0x00, 0x00, 0x00, 0x00, 0xF8, 0x7F, 0x00, 0x00, 0x00, 0x00,
  0x00, 0x00, 0x00, 0x00, 0x00, 0x00, 0x00, 0x00, 0x00, 0x00, 0xC0, 0xFF,
  0x03, 0x00, 0x00, 0x00, 0x00, 0x00, 0x00, 0x00, 0x00, 0x00, 0x00, 0x00,
  0x00, 0x00, 0x00, 0xFE, 0x1F, 0x00, 0x00, 0x00, 0xE0, 0x03, 0x70, 0x00,
  0x00, 0x00, 0x00, 0x00, 0x00, 0x00, 0x00, 0xE0, 0xFF, 0x00, 0x00, 0x00,
  0xE0, 0x07, 0x70, 0x00, 0x00, 0x00, 0x00, 0x00, 0x00, 0x00, 0x00, 0x00,
  0xFE, 0x07, 0x00, 0x00, 0xE0, 0x07, 0xF8, 0x00, 0x00, 0x00, 0x00, 0x00,
  0x00, 0x00, 0x00, 0x00, 0xE0, 0x1F, 0x00, 0x00, 0xC0, 0x07, 0xF0, 0x01,
  0x00, 0x00, 0x00, 0x00, 0x00, 0x00, 0x00, 0x00, 0x00, 0xFF, 0x00, 0x00,
  0xC0, 0x0F, 0xF8, 0x01, 0x00, 0x00, 0x00, 0x00, 0x00, 0x00, 0x00, 0x00,
  0x00, 0xF8, 0x03, 0x00, 0xC0, 0x0F, 0xF0, 0x01, 0x00, 0x00, 0x00, 0x00,
  0x00, 0x00, 0x00, 0x00, 0x00, 0xE0, 0x0F, 0x00, 0xC0, 0x0F, 0xF0, 0x03,
  0x00, 0x00, 0x00, 0x00, 0x00, 0x00, 0x00, 0x00, 0x00, 0x80, 0x3F, 0x00,
  0x80, 0x0F, 0xF0, 0x03, 0x00, 0x00, 0x00, 0x00, 0x00, 0x00, 0x00, 0x00,
  0x00, 0x00, 0xFE, 0x00, 0x80, 0x0F, 0xE0, 0x03, 0x00, 0x00, 0x00, 0x00,
  0x00, 0x00, 0x00, 0x00, 0x00, 0x00, 0xF8, 0x03, 0x80, 0x0F, 0xE0, 0x03,
  0x00, 0x00, 0x00, 0x00, 0x00, 0x00, 0x00, 0x00, 0x00, 0x00, 0xF0, 0x07,
  0x80, 0x1F, 0xE0, 0x07, 0x00, 0x00, 0x00, 0x00, 0x00, 0x00, 0x00, 0x00,
  0x00, 0x00, 0xC0, 0x0F, 0x00, 0x1F, 0xC0, 0x07, 0x00, 0xF8, 0x00, 0x00,
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
};


// ================================================================
// ===               INTERRUPT DETECTION ROUTINE                ===
// ================================================================

void initializeAllDisplays() {
  for (int display_pin = 0; display_pin < 10; display_pin++) {
    pinMode (displays[display_pin], OUTPUT);
    digitalWrite(displays[display_pin], LOW);
  }
  oled.begin();
  oled.setFlipMode(0);
  for (int display_pin = 0; display_pin < 10; display_pin++) {
    pinMode (displays[display_pin], OUTPUT);
    digitalWrite(displays[display_pin], HIGH);
  }
}

int layer = 9;
long stime = 0;

void setup() {

  pinMode(PIEZO, OUTPUT);
  digitalWrite(PIEZO, LOW);

#if I2CDEV_IMPLEMENTATION == I2CDEV_ARDUINO_WIRE
  Wire.begin();
#elif I2CDEV_IMPLEMENTATION == I2CDEV_BUILTIN_FASTWIRE
  Fastwire::setup(400, true);
#endif


  Serial.begin(115200);
  //while (!Serial);

  Serial.println("Initializing I2C devices...");
  accelgyro.initialize();

  Serial.println("Testing device connections...");
  Serial.println(accelgyro.testConnection() ? "MPU6050 connection successful" : "MPU6050 connection failed");

  initializeAllDisplays();
  oled_prepare();
  stime = millis();

  drawWaveDisplay(27, 25, 0);


}

int dir = 0;
int animation = 0;
int max_menu = 9;
int rotateTrig = 0;
int rotateOffset = 0;
int squareXOffset = 0;
int squareYOffset = 0;
int squareXDir = 1;
int squareYDir = 1;
byte xory = 0;
int bounce = 0;
int order[10] = {8, 0, 2, 3, 4, 5, 6, 7, 9, 1};

void loop() {
  //  Uncomment to use accelerometer data
  //accelgyro.getMotion6(&ax, &ay, &az, &gx, &gy, &gz);

  // drawRandomFill();

  if (millis() - stime > 7000) {
    animation++;
    if (animation > max_menu) {
      animation = 0;
    }
    if (animation == 2) {

      vel_xyz[0] = random(5000, 7000);
      vel_xyz[1] = random(5000, 7000);
      vel_xyz[2] = random(500, 1000);

    }
    clearVolumeBuffer();
    drawVolumeBuffer();
    stime = millis();
    bounce = 0;
  }
  switch (order[animation]) {
    case 0:
      {
        for (int i = 0; i < 10; i++) {
          if (layer == i) {
            drawWaveDisplay(25 + i, 25, i);
            //tick();
          }
          drawRecDisplay(64, 28, i + 54, i + 18,  9 - i);
        }
        layer--;
        if (layer < 0) {
          layer = 9;
        }
        drawVolumeBuffer();
        break;
      }
    case 1:
      {
        for (int display_num = 0; display_num < 10; display_num++) {
          startDrawDisplay(display_num);
          //oled.drawStr( 30, 20, "Hello World");
          drawSH();
          endDrawDisplay(display_num);
          delay(70);
          clearDisplayZ(display_num);

        }
        for (int display_num = 9; display_num >= 0; display_num--) {
          startDrawDisplay(display_num);
          drawSH();
          endDrawDisplay(display_num);
          delay(70);
          clearDisplayZ(display_num);
        }
        break;
      }
    case 2://3D BOUCING BALL
      {
        int acc[3] = {5, 2, 1};
        int scaled_xyz[3] = {0, 0, 0};
        for (int axis = 0; axis < 3; axis++) {
          vel_xyz[axis] += acc[axis];
          ball_xyz[axis] += vel_xyz[axis];
          if (axis < 2) {
            if (ball_xyz[axis] > (max_xyz[axis] - ball_r)) {
              ball_xyz[axis] = max_xyz[axis] - ball_r;
              vel_xyz[axis] /= float(-1.2);

            }
            if (ball_xyz[axis] < (1 + ball_r)) {
              ball_xyz[axis] = 1 + ball_r;
              vel_xyz[axis] /= float(-1.2);

            }
          }
          if (axis == 2) {
            if (ball_xyz[axis] > (max_xyz[axis])) {
              ball_xyz[axis] = max_xyz[axis];
              vel_xyz[axis] /= float(-1.2);

            }
            if (ball_xyz[axis] < 1) {
              ball_xyz[axis] = 1;
              vel_xyz[axis] /= float(-1.2);

            }
          }
          scaled_xyz[axis] = ball_xyz[axis] / 1000;
        }
        Serial.print(vel_xyz[0]);
        Serial.print(", ");
        Serial.print(vel_xyz[1]);
        Serial.print(", ");
        Serial.println(vel_xyz[2]);
        drawCircleDisplay(scaled_xyz[0], scaled_xyz[1], ball_r / 1000, scaled_xyz[2]);
        for (int i = 0; i < 10; i++) {
          drawRecDisplay(64, 27, 63, 27,  9 - i);
        }
        drawVolumeBuffer();
        startDrawDisplay(9);
        oled.drawBox(0, 0, 127, 55);
        endDrawDisplay(9);
        //Serial.println(millis()-stime);
        clearVolumeBuffer();

        break;
      }
    case 3://Random FILL Pixels
      {
        drawRandomFill();
        drawVolumeBuffer();
        delay(70);
        break;
      }

    case 4://LINES
      {
        int x_location[40];
        int z_location[40];
        int y_location[40];
        for (int numLines = 0; numLines < 40; numLines++) {
          z_location[numLines] = random(9);
          x_location[numLines] = random(127);
          y_location[numLines] = random(55);
        }
        for (int display_num = 0; display_num < 10; display_num++) {
          startDrawDisplay(display_num);
          for (int numLines = 0; numLines < 40; numLines++) {
            if (z_location[numLines] == display_num) {
              int randx = random(127);
              int randy = random(55);
              oled.drawLine(x_location[numLines], 0, x_location[numLines], 55);
            }
          }
          endDrawDisplay(display_num);
          delay(70);
        }
        break;
      }
    case 5:
      {
        int cx = 64;
        int cy = 30;

        int trisize = 20;
        int px[3] = {0, 0, 0};
        int py[3] = {0, 0, 0};
        int tempx = 0;
        int tempy = 0;
        int angle[3] = {0, 120, 240};
        for (int display_num = 0; display_num < 9; display_num++) {
          for (int j = 0; j < 3; j++) {
            float rad = (float(angle[j] + rotateTrig + (display_num * rotateOffset)) * 71) / 4068;
            //Serial.println(rad);
            rotate_point(cx, cy, rad, tempx, tempy, trisize);
            px[j] = tempx;
            py[j] = tempy;
          }
          startDrawDisplay(display_num);
          //if (display_num == layer) {
          //  oled.drawCircle(cx, cy, trisize, U8G2_DRAW_ALL);
          //}
          //else {
          oled.drawLine(px[1], py[1], px[2], py[2]);
          oled.drawLine(px[0], py[0], px[1], py[1]);
          oled.drawLine(px[0], py[0], px[2], py[2]);
          //}
          endDrawDisplay(display_num);
          if ((rotateTrig % 35) == 0) {
            layer--;
            if (layer < 0) {
              layer = 9;
            }
          }
        }
        delay(10);
        break;
      }
    case 6:
      {
        for (int display_num = 0; display_num < 9; display_num++) {
          startDrawDisplay(display_num);
          int shrinkx = (display_num * 6);
          int shrinky = (display_num * 2);
          int xO = squareXOffset * display_num / 4;
          int yO = squareYOffset * display_num / 8;
          oled.drawRFrame(0 + shrinkx + (xO * 2), 0 + shrinky + (yO * 2), 127 - shrinkx * 2 + xO, 55 - shrinky * 2 + yO, 10 - display_num);
          endDrawDisplay(display_num);
        }
        delay(50);
        if (xory == 1) {
          squareXOffset += squareXDir;
          if ((squareXOffset > 3) || (squareXOffset < -3)) {
            squareXDir *= -1;
            xory = 0;
          }
        }
        else {
          squareYOffset += squareYDir;
          if ((squareYOffset > 3) || (squareYOffset < -3)) {
            squareYDir *= -1;
            xory = 1;
          }
        }
        break;
      }
    case 7:
      {
        accelgyro.getMotion6(&ax, &ay, &az, &gx, &gy, &gz);
        int xc = 64;
        int yc = 30;
        int d = 25;

        int bd = d * 1000;
        int acc[3] = {0, 0, 0};

        acc[0] = ay / 50;
        acc[1] = az / 50;
        acc[2] = ax / 50;

        if (bounce == 0) {
          acc[1] = random(3000, 5000);
          acc[0] = random(-6000, 6000);
          bounce = 1;
        }

        int scaled_xyz[3] = {64, 30, 5};
        for (int axis = 0; axis < 2; axis++) {
          vel_xyz[axis] += acc[axis];
          ball_xyz[axis] += vel_xyz[axis];
          if (axis < 2) {
            if (ball_xyz[axis] > (max_xyz[axis] - bd)) {
              ball_xyz[axis] = max_xyz[axis] - bd;
              vel_xyz[axis] /= float(-1.2);
            }
            if (ball_xyz[axis] < (1 + bd)) {
              ball_xyz[axis] = 1 + bd;
              vel_xyz[axis] /= float(-1.2);

            }

            if (ball_xyz[axis] < 1) {
              ball_xyz[axis] = 1;
              vel_xyz[axis] /= float(-1.2);
            }
          }
          scaled_xyz[axis] = ball_xyz[axis] / 1000;
        }

        //        if(vel_xyz[1] < 10){
        //          bounce = 0;
        //        }



        xc = scaled_xyz[0];
        yc = scaled_xyz[1];

        drawCircleDisplay(xc, yc, d, 4);
        drawCircleDisplay(xc, yc, d - 2, 5);
        drawCircleDisplay(xc, yc, d - 4, 6);
        drawCircleDisplay(xc, yc, d - 8, 7);
        drawCircleDisplay(xc, yc, d - 16, 8);
        drawCircleDisplay(xc, yc, d - 22, 9);
        drawCircleDisplay(xc, yc, d - 2, 3);
        drawCircleDisplay(xc, yc, d - 4, 2);
        drawCircleDisplay(xc, yc, d - 8, 1);
        drawCircleDisplay(xc, yc, d - 16, 0);
        drawCircleDisplay(xc, yc, d - 22, 0);

        drawVolumeBuffer();
        break;
      }
    case 8:
    { for (int display_num = 0; display_num < 10; display_num++) {
          startDrawDisplay(display_num);
          oled.drawBox(0, 0, 127, 55);
          endDrawDisplay(display_num);
          delay(100);
          clearDisplayZ(display_num);

        }
        break;
      }
    case 9:
      { 
        for (int display_num = 9; display_num >= 0; display_num--) {
          startDrawDisplay(display_num);
          drawSH();
          endDrawDisplay(display_num);
          delay(700);
          if (display_num == 0){
            delay(10000);
          }
          clearDisplayZ(display_num);
        }
        break;
      }
    default:
      break;
  }
  rotateTrig += 7;
  rotateOffset += 1;
  clearVolumeBuffer();
}



void oled_prepare(void) {
  oled.setFont(u8g2_font_6x10_tf);
  oled.setFontRefHeightExtendedText();
  oled.setDrawColor(1);
  oled.setFontPosTop();
  oled.setFontDirection(0);
}

void drawVolumeBuffer() {
  int axis_res[3] = {X_RES, Y_RES, Z_RES};
  for (int display_num = 0; display_num < 10; display_num++) {
    digitalWrite(displays[display_num], LOW);
    oled.clearBuffer();
    for (int y = 0; y < Y_RES; y++) {
      for (int x = 0; x < X_RES; x++) {
        if (volumeBuffer[x][y][display_num] == 1) {
          oled.drawPixel(x, y);
        }
      }
    }
    oled.sendBuffer();
    digitalWrite(displays[display_num], HIGH);
  }
}

void clearVolumeBuffer() {
  for (int z = 0; z < Z_RES; z++) {
    for (int y = 0; y < Y_RES; y++) {
      for (int x = 0; x < X_RES; x++) {
        volumeBuffer[x][y][z] = 0;
      }
    }
  }
}

void clearDisplayZ(int d_num) {
  digitalWrite(displays[d_num], LOW);
  oled.clear();
  digitalWrite(displays[d_num], HIGH);
}

void startDrawDisplay(int d_num) {
  digitalWrite(displays[d_num], LOW);
  oled.clearBuffer();
}

void endDrawDisplay(int d_num) {
  oled.sendBuffer();
  digitalWrite(displays[d_num], HIGH);
}


void drawCircleDisplay(int x_center, int y_center, float r, int d_num) {
  for (int angle = 0; angle < 360; angle++) {
    float angle_circle = (angle * 0.01745331);      // angle expressed in radians - 1 degree = 0,01745331 radians
    float x_edge = (x_center + (r * cos(angle_circle)));
    float y_edge = (y_center + (r * sin(angle_circle)));
    int x = int(x_edge);
    int y = int(y_edge);
    volumeBuffer[x][y][d_num] = 1;
  }
}

void drawRecDisplay(int x_center, int y_center, float lx, float ly, int d_num) {
  int rangex = int(lx);
  int rangey = int(ly);
  for (int x = (-rangex); x < (rangex + 1); x++) {
    volumeBuffer[x_center - x][y_center + rangey][d_num] = 1;
    volumeBuffer[x_center - x][y_center - rangey][d_num] = 1;
  }
  for (int y = (-rangey); y < (rangey + 1); y++) {
    volumeBuffer[x_center + rangex][y_center - y][d_num] = 1;
    volumeBuffer[x_center - rangex][y_center - y][d_num] = 1;
  }
}

void draw3DLine(int xs, int ys, int zs, int xe, int ye, int ze) {

}

void drawSphere(int xloc, int yloc, int zloc, int r) {
  int displayNum = r / 2;
  for (int z = 0; z < displayNum; z++) {
    for (int y = 0; y < Y_RES; y++) {
      for (int x = 0; x < X_RES; x++) {
      }
    }
  }
}

void drawWaveDisplay(int center, int range, int d_num) {
  int points[9] = {0, 0, 0, 0, 0, 0, 0, 0, 0};
  for (int point_num = 0; point_num < 9; point_num++) {
    points[point_num] = center + random(-range, range);
    points[point_num] = constrain(points[point_num], 0, 55);
    //Serial.println(points[point_num]);
  }
  int near_point = 0;
  int wave = points[0];
  int lastwave = points[0];
  volumeBuffer[0][wave][d_num] = 1;
  // Serial.println("Test");
  for (int x_location = 0; x_location < 128; x_location++) {
    if (x_location > 15) {
      int modulo = (x_location) % 16;
      //      Serial.print(modulo);
      //      Serial.print(", ");
      if (modulo == 0) {
        near_point++;
      }
    }
    else {

    }
    wave = float(0.1) * points[near_point] + float(0.9) * lastwave;
    //    Serial.print(near_point);
    //    Serial.print(", ");
    //    Serial.print(x_location);
    //    Serial.print(", ");
    //Serial.println(wave);
    lastwave = wave;
    volumeBuffer[x_location][wave][d_num] = 1;
  }
}

void drawRandomFill() {
  randomSeed(analogRead(A6));
  Serial.println("Randomly selecting pixels");
  for (int pixels = 0; pixels < 1000; pixels++) {
    int xpix = random(X_RES);
    int ypix = random(Y_RES);
    int zpix = random(Z_RES);
    volumeBuffer[xpix][ypix][zpix] = 1;
  }
}

void drawSH(void)
{
  uint8_t mdy = 0;
  if ( oled.getDisplayHeight() < 59 )
    mdy = 5;
  oled.drawXBM(0, 0, SH_width, SH_height, SH);
}

void tick() {
  digitalWrite(PIEZO, HIGH);
  delayMicroseconds(200);
  digitalWrite(PIEZO, LOW);
}

void rotate_point(int cx, int cy, float angle, int &px, int &py, int trisize)
{
  float fpx = float(cx + trisize);
  float fpy = float(cy + trisize);
  float s = sin(angle);
  float c = cos(angle);

  // translate point back to origin:
  fpx -= float(cx);
  fpy -= float(cy);

  // rotate point
  float xnew = fpx * c - fpy * s;
  float ynew = fpx * s + fpy * c;

  // translate point back:
  fpx = xnew + float(cx);
  fpy = ynew + float(cy);
  px = int(fpx);
  py = int(fpy);

}

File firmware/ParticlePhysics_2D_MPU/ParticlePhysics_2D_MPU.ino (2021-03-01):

//--------------------------------------------------------------------------
// This code is modified from the following Adafruit tutorial: https://learn.adafruit.com/animated-led-sand/overview
/*

    This code is modified from the following Adafruit tutorial: https://learn.adafruit.com/animated-led-sand/overview
    This program shows an upvote arrow 3 times then on the 4th it breaks into particles that will move based on accelerometer readings.
*/

#include <Arduino.h>
#include <math.h>

#include "I2Cdev.h"
#include "MPU6050.h"


#if I2CDEV_IMPLEMENTATION == I2CDEV_ARDUINO_WIRE
#include "Wire.h"
#endif

MPU6050 mpu;

#include <U8g2lib.h>

#ifdef U8X8_HAVE_HW_SPI
#include <SPI.h>
#endif
#ifdef U8X8_HAVE_HW_I2C
#include <Wire.h>
#endif


int displays [10] = {A0, A1, A2, A3, A4, A5, 10, 9, 6, 5};
U8G2_SSD1309_128X64_NONAME0_F_4W_HW_SPI oled(U8G2_MIRROR, /* cs=*/ 4, /* dc=*/ 11, /* reset=*/ 13);

//int N_GRAINS = 0;
#define N_GRAINS     100 // Number of grains of sand
#define WIDTH        128 // Display width in pixels
#define HEIGHT       56 // Display height in pixels
#define MAX_FPS      60 
#define SCALE        128
#define WBOUNCE      -2
#define BBOUNCE      -2

#define MAX_X (WIDTH  * SCALE - 1) 
#define MAX_Y (HEIGHT * SCALE - 1) 
struct Grain {
  int16_t  x,  y; 
  int16_t vx, vy; 
} grain[N_GRAINS];

int16_t rax, ray, raz;
int16_t rgx, rgy, rgz;
uint32_t        prevTime   = 0;      
uint8_t         backbuffer = 0,      
                img[WIDTH * HEIGHT];


void setup(void) {
  uint8_t i, j, bytes;
  for (int display_pin = 0; display_pin < 10; display_pin++) {

    pinMode (displays[display_pin], OUTPUT);
    digitalWrite(displays[display_pin], LOW);
  }
  Serial.begin(115200);

#if I2CDEV_IMPLEMENTATION == I2CDEV_ARDUINO_WIRE
  Wire.begin();
#elif I2CDEV_IMPLEMENTATION == I2CDEV_BUILTIN_FASTWIRE
  Fastwire::setup(400, true);
#endif
  Serial.println("Initializing I2C devices...");
  mpu.initialize();
  Serial.println("Testing device connections...");
  Serial.println(mpu.testConnection() ? "MPU6050 connection successful" : "MPU6050 connection failed");

  oled.begin();
  oled.setFlipMode(0);
  u8g2_prepare();
  for (int display_pin = 0; display_pin < 10; display_pin++) {
    pinMode (displays[display_pin], OUTPUT);
    digitalWrite(displays[display_pin], HIGH);
  }
  memset(img, 0, sizeof(img)); // Clear the img[] array
  int grain_num = 0;
  for (int x = 0; x < 256; x++) {
      int NX = x % 128;
      int NY = x / 56;
      grain[grain_num].x = (NX  * SCALE); // Assign random position within
      grain[grain_num].y = (NY * SCALE);
      grain_num++;
  }

  for (i = 0; i < N_GRAINS; i++) { // For each sand grain...
    img[(grain[i].y / SCALE) * WIDTH + (grain[i].x / SCALE)] = 255; // Mark it
    grain[i].vx = grain[i].vy = 0; // Initial velocity is zero
  }
}


void loop() {
  digitalWrite(5, LOW);
  uint32_t t;
  while (((t = micros()) - prevTime) < (1000000L / MAX_FPS));
  prevTime = t;
  

  backbuffer = 1 - backbuffer; // Swap front/back buffer index

  // Read accelerometer...
  mpu.getMotion6(&rax, &ray, &raz, &rgx, &rgy, &rgz);
  //randomSeed(A6);

  int16_t ax = -ray / SCALE,      // Transform accelerometer axes
          ay = raz / SCALE,      // to grain coordinate space
          az = abs(rax) / SCALE; // Random motion factor

//  Serial.print(ax);
//  Serial.print(",");
//  Serial.print(ay);
//  Serial.print(",");
//  Serial.println(az);

  az = (az >= 3) ? 1 : 4 - az;      // Clip & invert
  ax -= az;                         // Subtract motion factor from X, Y
  ay -= az;
  long az2 = az * 2 + 1;         // Range of random motion to add back in


  int32_t v2; // Velocity squared
  float   v;  // Absolute velocity
  for (int i = 0; i < N_GRAINS; i++) {
    grain[i].vx += ax + random(az2); // A little randomness makes
    grain[i].vy += ay + random(az2); // tall stacks topple better!

    v2 = (int32_t)grain[i].vx * grain[i].vx + (int32_t)grain[i].vy * grain[i].vy;
    if (v2 > 65536) { // If v^2 > 65536, then v > SCALE
      v = sqrt((float)v2); // Velocity vector magnitude
      grain[i].vx = (int)(SCALE * (float)grain[i].vx / v); // Maintain heading
      grain[i].vy = (int)(SCALE * (float)grain[i].vy / v); // Limit magnitude
    }
  }

  uint8_t        i, bytes, oldidx, newidx, delta;
  int16_t        newx, newy;
  // const uint8_t *ptr = remap;

  //randomSeed(A6);
  int list[N_GRAINS];
  for (int num = 0; num < N_GRAINS; num++) {
    list[num] = num;
  }
  for (int a = 0; a < N_GRAINS; a++)
  {
    int r = random(a, (N_GRAINS));
    int temp = list[a];
    list[a] = list[r];
    list[r] = temp;
  }


  for (i = 0; i < N_GRAINS; i++) {
    newx = grain[list[i]].x + grain[list[i]].vx;
    newy = grain[list[i]].y + grain[list[i]].vy;
    if (newx > MAX_X) {
      newx         = MAX_X;
      grain[list[i]].vx /= WBOUNCE;
    } else if (newx < 0) {
      newx         = 0;
      grain[list[i]].vx /= WBOUNCE;
    }
    if (newy > MAX_Y) {
      newy         = MAX_Y;
      grain[list[i]].vy /= WBOUNCE;
    } else if (newy < 0) {
      newy         = 0;
      grain[list[i]].vy /= WBOUNCE;
    }

    oldidx = (grain[list[i]].y / SCALE) * WIDTH + (grain[list[i]].x / SCALE);
    newidx = (newy      / SCALE) * WIDTH + (newx      / SCALE);
    if ((oldidx != newidx) &&
        img[newidx]) {
      delta = abs(newidx - oldidx);
      Serial.println(delta);
      if (delta == 1) {
        newx         = grain[list[i]].x;
        grain[list[i]].vx /= BBOUNCE;
        newidx       = oldidx;
      } else if (delta == WIDTH) {
        newy         = grain[list[i]].y;
        grain[list[i]].vy /= BBOUNCE;
        newidx       = oldidx;
      } else {
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

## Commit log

2021-03-01 Its OCF
    [694106301002 (rev1).stp, Head_Arm.stl, Head_Holder_Single.stl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]
2021-03-02 Added BOM
    [TENEX_BOM.csv, feather_multi_oled.sch]
2021-03-04 added Display Top and STP
    [Display_Top (Acrylic).step, Display_Top (lasercut if possible).stl, OLED_Holder.stl]
2024-07-09 updated BOM for new 24 Pin FCP Connector P/N
    [525592452.stp, c-2-1734742-4-o-3d.stp, feather_multi_oled.csv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]

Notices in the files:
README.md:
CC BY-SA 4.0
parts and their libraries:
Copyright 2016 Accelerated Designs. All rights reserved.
